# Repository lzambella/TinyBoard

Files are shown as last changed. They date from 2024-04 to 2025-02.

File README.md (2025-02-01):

40% keyboard based on a layout I found somewhere, possibly Reddit, and modified for my own tastes. Runs on TMK firmware.

**Switches**
Uses any Cherry full size 5-hole compatible ones. I like to use Gateron North Poles.

LEDs should be 1206 package.

TODO:
* Add STEP files for 3d printing/designing
* PDF files of schematics
* Better docs
* images
* how to build one?

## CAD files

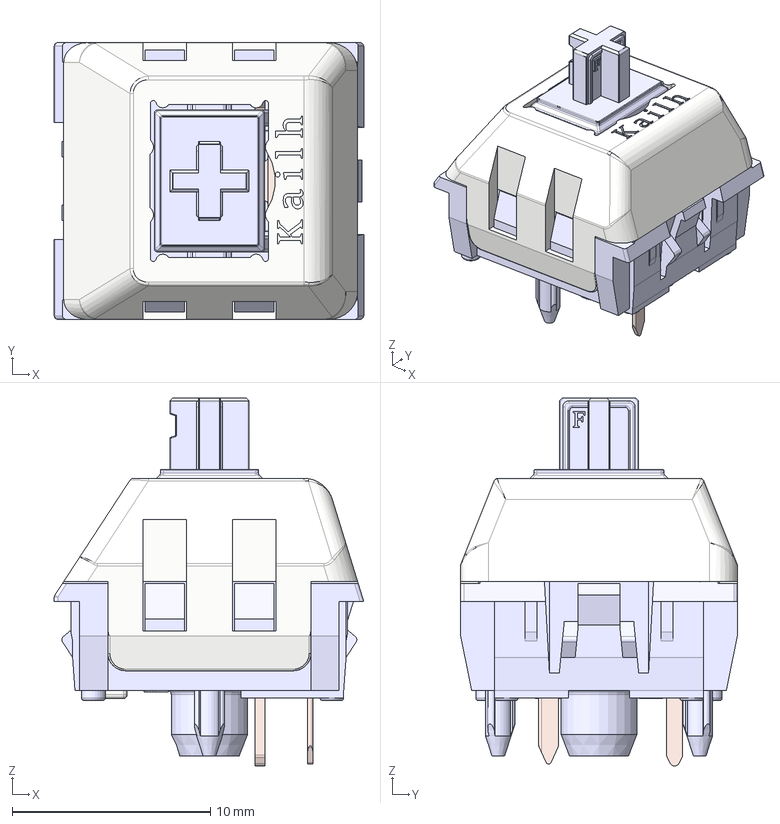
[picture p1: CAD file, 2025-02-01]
schematics/STEP files/KeySwitch.step
15.6 x 14.0 x 18.5 mm
Housing
ThickContact
SpringContact
Stem
Lid

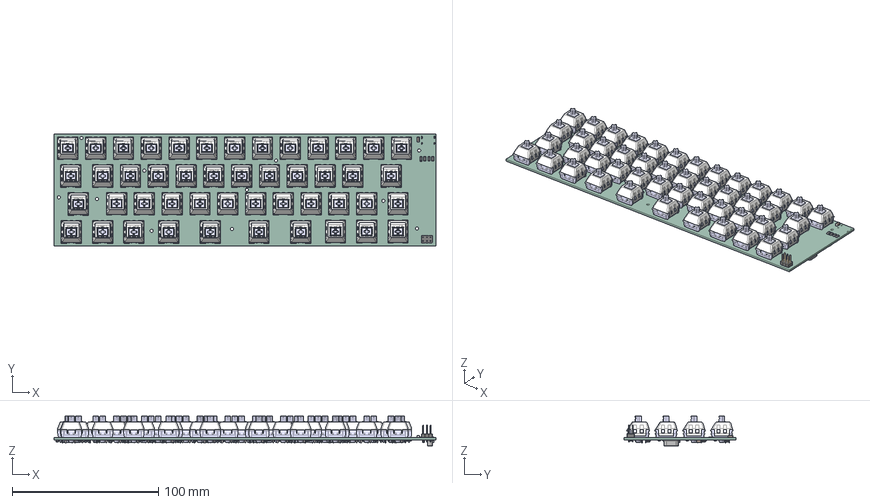
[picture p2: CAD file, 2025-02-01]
schematics/STEP files/PCB.step
261.1 x 76.2 x 20.4 mm
LED_1206_3216Metric x 47
Kailh Polia v86 x 47
C_1206_3216Metric x 4
R_1206_3216Metric x 51
PinHeader_2x03_P254mm_Vertical
D_SOD_123 x 47
Crystal_SMD_HC49-SD
_autosave-40 Keyboard_PCB

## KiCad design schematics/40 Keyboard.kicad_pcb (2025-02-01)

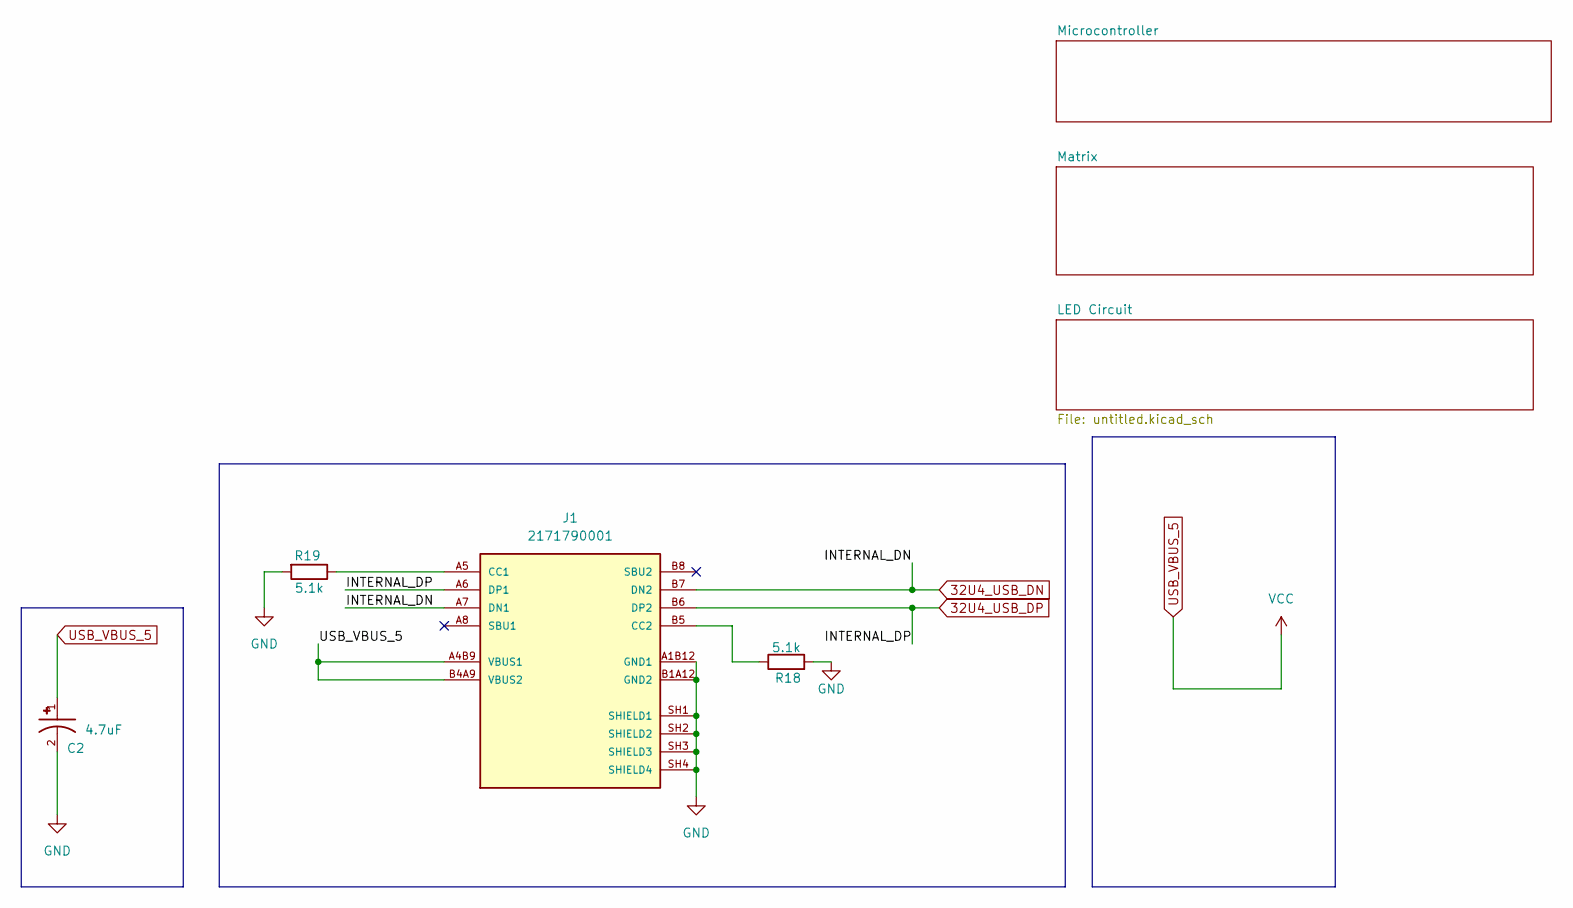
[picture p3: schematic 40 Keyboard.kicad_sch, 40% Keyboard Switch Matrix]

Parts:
C2: 4.7uF; C_1206_3216Metric_Pad1.33x1.80mm_HandSolder; Part # 311-2011-1-ND
J1: 2171790001; MOLEX_2171790001; PARTREV A1
R18, R19: 5.1k; R_1206_3216Metric; Part # RMCF1206JT5K10

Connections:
32U4_USB_DN: J1.A7 (DN1), J1.B7 (DN2); also elsewhere on the board
32U4_USB_DP: J1.A6 (DP1), J1.B6 (DP2); also elsewhere on the board
GND: C2.2, J1.A1B12 (GND1), J1.B1A12 (GND2), J1.SH1 (SHIELD1), J1.SH2 (SHIELD2), J1.SH3 (SHIELD3), J1.SH4 (SHIELD4), R18.2, R19.2; also elsewhere on the board
unnamed: J1.A5 (CC1), R19.1
unnamed: J1.B5 (CC2), R18.1
USB_VBUS_5: C2.1, J1.A4B9 (VBUS1), J1.B4A9 (VBUS2); also elsewhere on the board

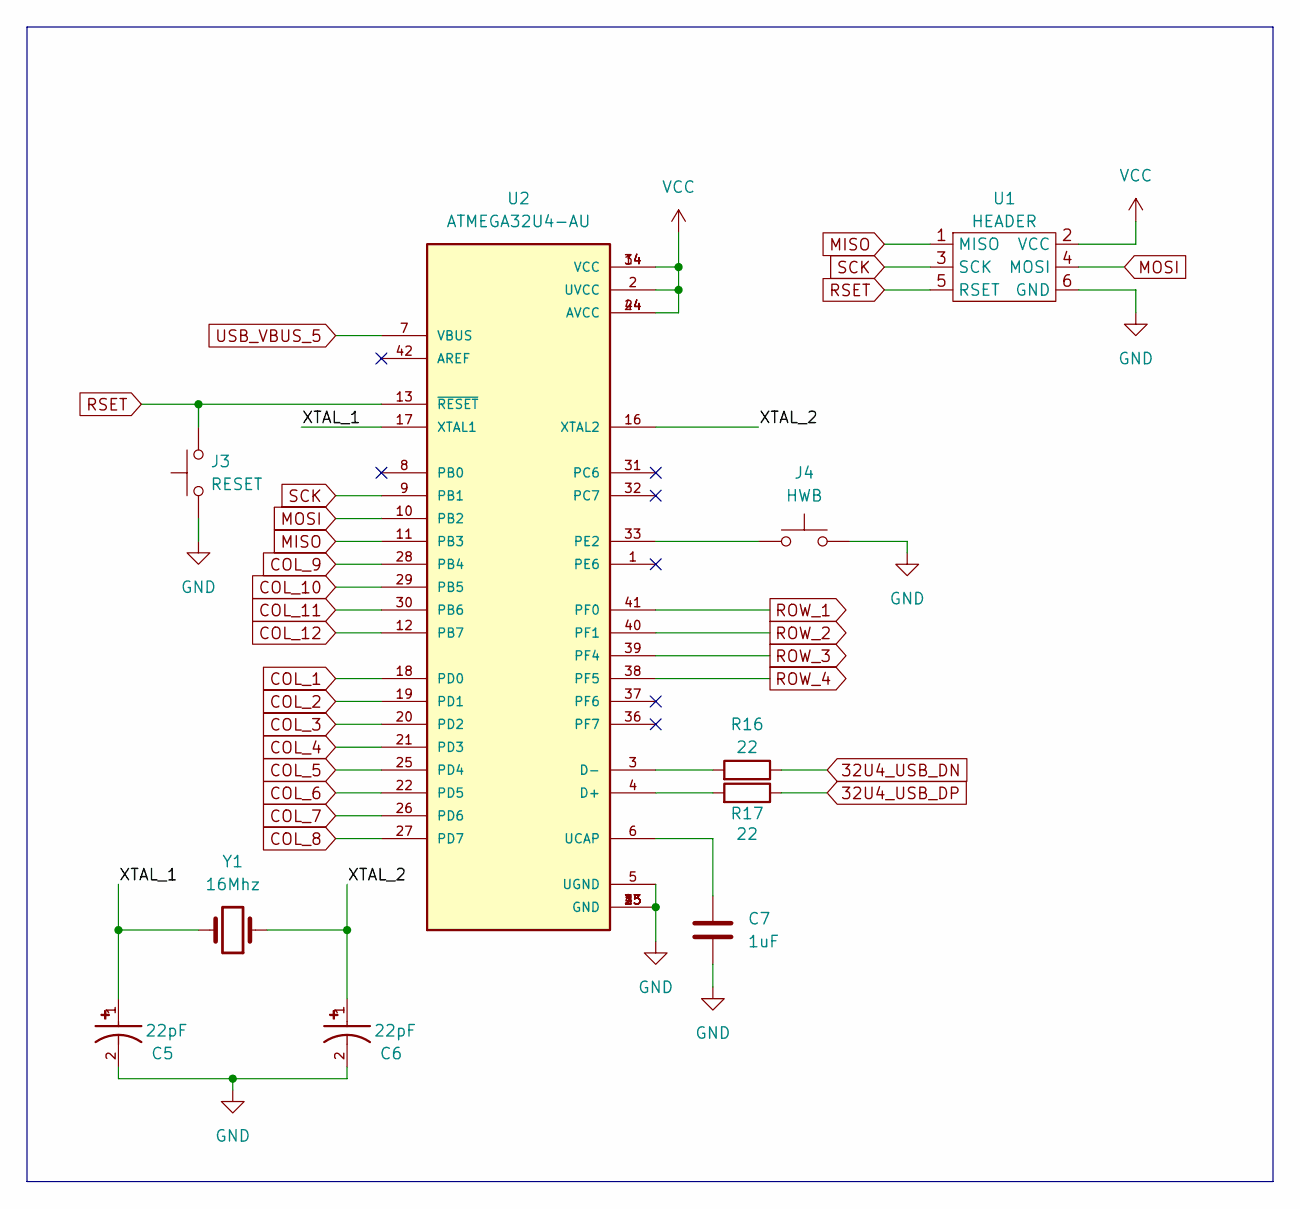
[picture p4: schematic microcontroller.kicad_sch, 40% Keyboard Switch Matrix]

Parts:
C5, C6: C1206C220K3HAC7800; C_1206_3216Metric_Pad1.33x1.80mm_HandSolder; Part # C1206C220K3HAC7800
C7: 1uF; C_1206_3216Metric; Part # C1206C104K5RAC7800
J3: RESET; SolderJumper-2_P1.3mm_Open_Pad1.0x1.5mm
J4: HWB; SolderJumper-2_P1.3mm_Open_Pad1.0x1.5mm
R16, R17: 22; R_1206_3216Metric; Part # RMCF1206JT22R0
U1: HEADER; PinHeader_2x03_P2.54mm_Vertical; Part # PH2-06-UA
U2: ATMEGA32U4-AU; atmega32u4; Part # ATMEGA32U4-AU-ND
Y1: 16Mhz; Crystal_SMD_HC49-SD_HandSoldering; Part # J49SMH-A-G-G-K-16M0

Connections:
32U4_USB_DN: R16.1; also elsewhere on the board
32U4_USB_DP: R17.1; also elsewhere on the board
/Microcontroller/XTAL_1: C5.1, U2.17 (XTAL1), Y1.2
/Microcontroller/XTAL_2: C6.1, U2.16 (XTAL2), Y1.1
COL_1: U2.18 (PD0); also elsewhere on the board
COL_2: U2.19 (PD1); also elsewhere on the board
COL_3: U2.20 (PD2); also elsewhere on the board
COL_4: U2.21 (PD3); also elsewhere on the board
COL_5: U2.25 (PD4); also elsewhere on the board
COL_6: U2.22 (PD5); also elsewhere on the board
COL_7: U2.26 (PD6); also elsewhere on the board
COL_8: U2.27 (PD7); also elsewhere on the board
COL_9: U2.28 (PB4); also elsewhere on the board
COL_10: U2.29 (PB5); also elsewhere on the board
COL_11: U2.30 (PB6); also elsewhere on the board
COL_12: U2.12 (PB7); also elsewhere on the board
GND: C5.2, C6.2, C7.2, J3.1, J4.2, U1.6 (GND), U2.5 (UGND), U2.15 (GND), U2.23 (GND), U2.35 (GND), U2.43 (GND); also elsewhere on the board
MISO: U1.1 (MISO), U2.11 (PB3)
MOSI: U1.4 (MOSI), U2.10 (PB2)
unnamed: R17.2, U2.4 (D+)
unnamed: R16.2, U2.3 (D-)
unnamed: J4.1, U2.33 (PE2)
unnamed: C7.1, U2.6 (UCAP)
ROW_1: U2.41 (PF0); also elsewhere on the board
ROW_2: U2.40 (PF1); also elsewhere on the board
ROW_3: U2.39 (PF4); also elsewhere on the board
ROW_4: U2.38 (PF5); also elsewhere on the board
RSET: J3.2, U1.5 (RSET), U2.13 (~RESET)
SCK: U1.3 (SCK), U2.9 (PB1)
USB_VBUS_5: U1.2 (VCC), U2.2 (UVCC), U2.7 (VBUS), U2.14 (VCC), U2.24 (AVCC), U2.34 (VCC), U2.44 (AVCC); also elsewhere on the board

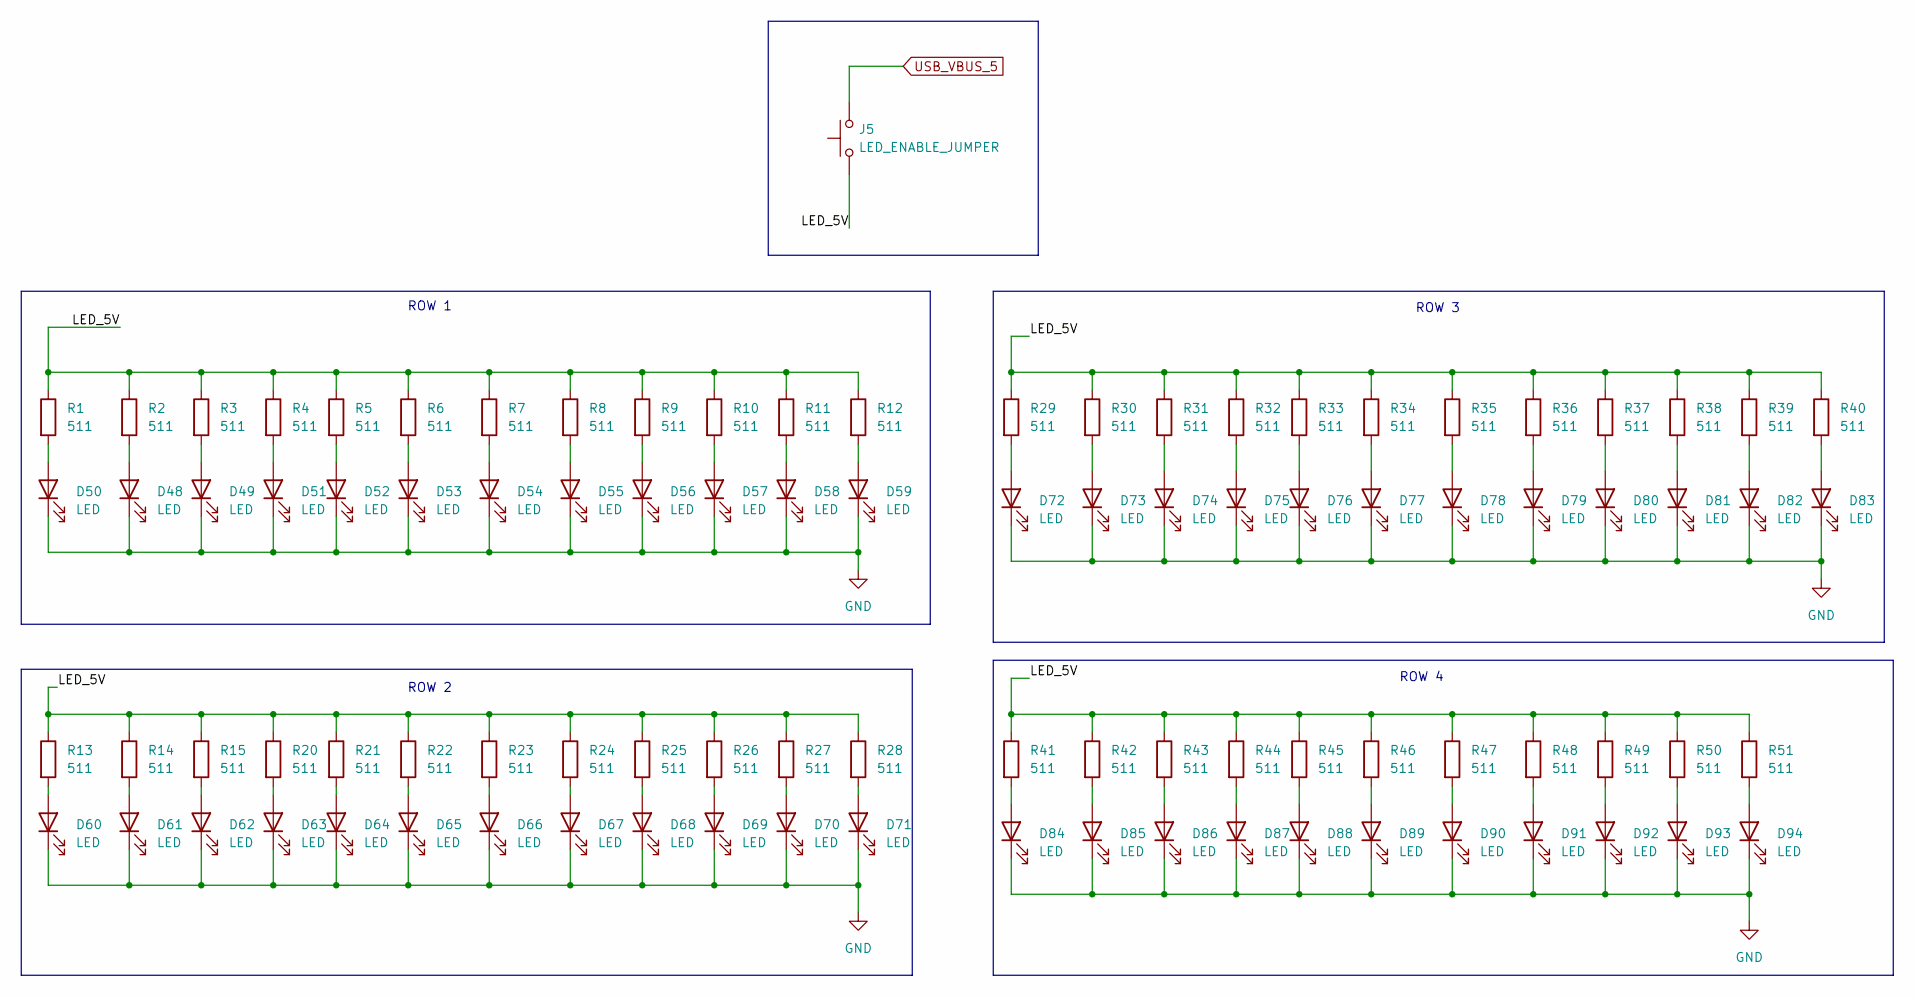
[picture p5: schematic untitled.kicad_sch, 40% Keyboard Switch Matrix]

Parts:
D48, D49, D50, D51, D52, D53, D54, D55, D56, D57, D58, D59, D60, D61, D62, D63, D64, D65, D66, D67, D68, D69, D70, D71, D72, D73, D74, D75, D76, D77, D78, D79, D80, D81, D82, D83, D84, D85, D86, D87, D88, D89, D90, D91, D92, D93, D94: LED; LED_1206_3216Metric_Pad1.42x1.75mm_HandSolder; Part # 732-4988-1-ND
J5: LED_ENABLE_JUMPER; SolderJumper-2_P1.3mm_Open_Pad1.0x1.5mm
R1, R2, R3, R4, R5, R6, R7, R8, R9, R10, R11, R12, R13, R14, R15, R20, R21, R22, R23, R24, R25, R26, R27, R28, R29, R30, R31, R32, R33, R34, R35, R36, R37, R38, R39, R40, R41, R42, R43, R44, R45, R46, R47, R48, R49, R50, R51: 511; R_1206_3216Metric_Pad1.30x1.75mm_HandSolder; Part # RNCP1206FTD511RCT-ND

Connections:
/LED Circuit/LED_5V: J5.1, R1.1, R2.1, R3.1, R4.1, R5.1, R6.1, R7.1, R8.1, R9.1, R10.1, R11.1, R12.1, R13.1, R14.1, R15.1, R20.1, R21.1, R22.1, R23.1, R24.1, R25.1, R26.1, R27.1, R28.1, R29.1, R30.1, R31.1, R32.1, R33.1, R34.1, R35.1, R36.1, R37.1, R38.1, R39.1, R40.1, R41.1, R42.1, R43.1, R44.1, R45.1, R46.1, R47.1, R48.1, R49.1, R50.1, R51.1
GND: D48.1 (K), D49.1 (K), D50.1 (K), D51.1 (K), D52.1 (K), D53.1 (K), D54.1 (K), D55.1 (K), D56.1 (K), D57.1 (K), D58.1 (K), D59.1 (K), D60.1 (K), D61.1 (K), D62.1 (K), D63.1 (K), D64.1 (K), D65.1 (K), D66.1 (K), D67.1 (K), D68.1 (K), D69.1 (K), D70.1 (K), D71.1 (K), D72.1 (K), D73.1 (K), D74.1 (K), D75.1 (K), D76.1 (K), D77.1 (K), D78.1 (K), D79.1 (K), D80.1 (K), D81.1 (K), D82.1 (K), D83.1 (K), D84.1 (K), D85.1 (K), D86.1 (K), D87.1 (K), D88.1 (K), D89.1 (K), D90.1 (K), D91.1 (K), D92.1 (K), D93.1 (K), D94.1 (K); also elsewhere on the board
unnamed: D48.2 (A), R2.2
unnamed: D49.2 (A), R3.2
unnamed: D50.2 (A), R1.2
unnamed: D51.2 (A), R4.2
unnamed: D52.2 (A), R5.2
unnamed: D53.2 (A), R6.2
unnamed: D54.2 (A), R7.2
unnamed: D55.2 (A), R8.2
unnamed: D56.2 (A), R9.2
unnamed: D57.2 (A), R10.2
unnamed: D58.2 (A), R11.2
unnamed: D59.2 (A), R12.2
unnamed: D60.2 (A), R13.2
unnamed: D61.2 (A), R14.2
unnamed: D62.2 (A), R15.2
unnamed: D63.2 (A), R20.2
unnamed: D64.2 (A), R21.2
unnamed: D65.2 (A), R22.2
unnamed: D66.2 (A), R23.2
unnamed: D67.2 (A), R24.2
unnamed: D68.2 (A), R25.2
unnamed: D69.2 (A), R26.2
unnamed: D70.2 (A), R27.2
unnamed: D71.2 (A), R28.2
unnamed: D72.2 (A), R29.2
unnamed: D73.2 (A), R30.2
unnamed: D74.2 (A), R31.2
unnamed: D75.2 (A), R32.2
unnamed: D76.2 (A), R33.2
unnamed: D77.2 (A), R34.2
unnamed: D78.2 (A), R35.2
unnamed: D79.2 (A), R36.2
unnamed: D80.2 (A), R37.2
unnamed: D81.2 (A), R38.2
unnamed: D82.2 (A), R39.2
unnamed: D83.2 (A), R40.2
unnamed: D84.2 (A), R41.2
unnamed: D85.2 (A), R42.2
unnamed: D86.2 (A), R43.2
unnamed: D87.2 (A), R44.2
unnamed: D88.2 (A), R45.2
unnamed: D89.2 (A), R46.2
unnamed: D90.2 (A), R47.2
unnamed: D91.2 (A), R48.2
unnamed: D92.2 (A), R49.2
unnamed: D93.2 (A), R50.2
unnamed: D94.2 (A), R51.2
USB_VBUS_5: J5.2; also elsewhere on the board

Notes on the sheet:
ROW 2
ROW 4
ROW 3
ROW 1

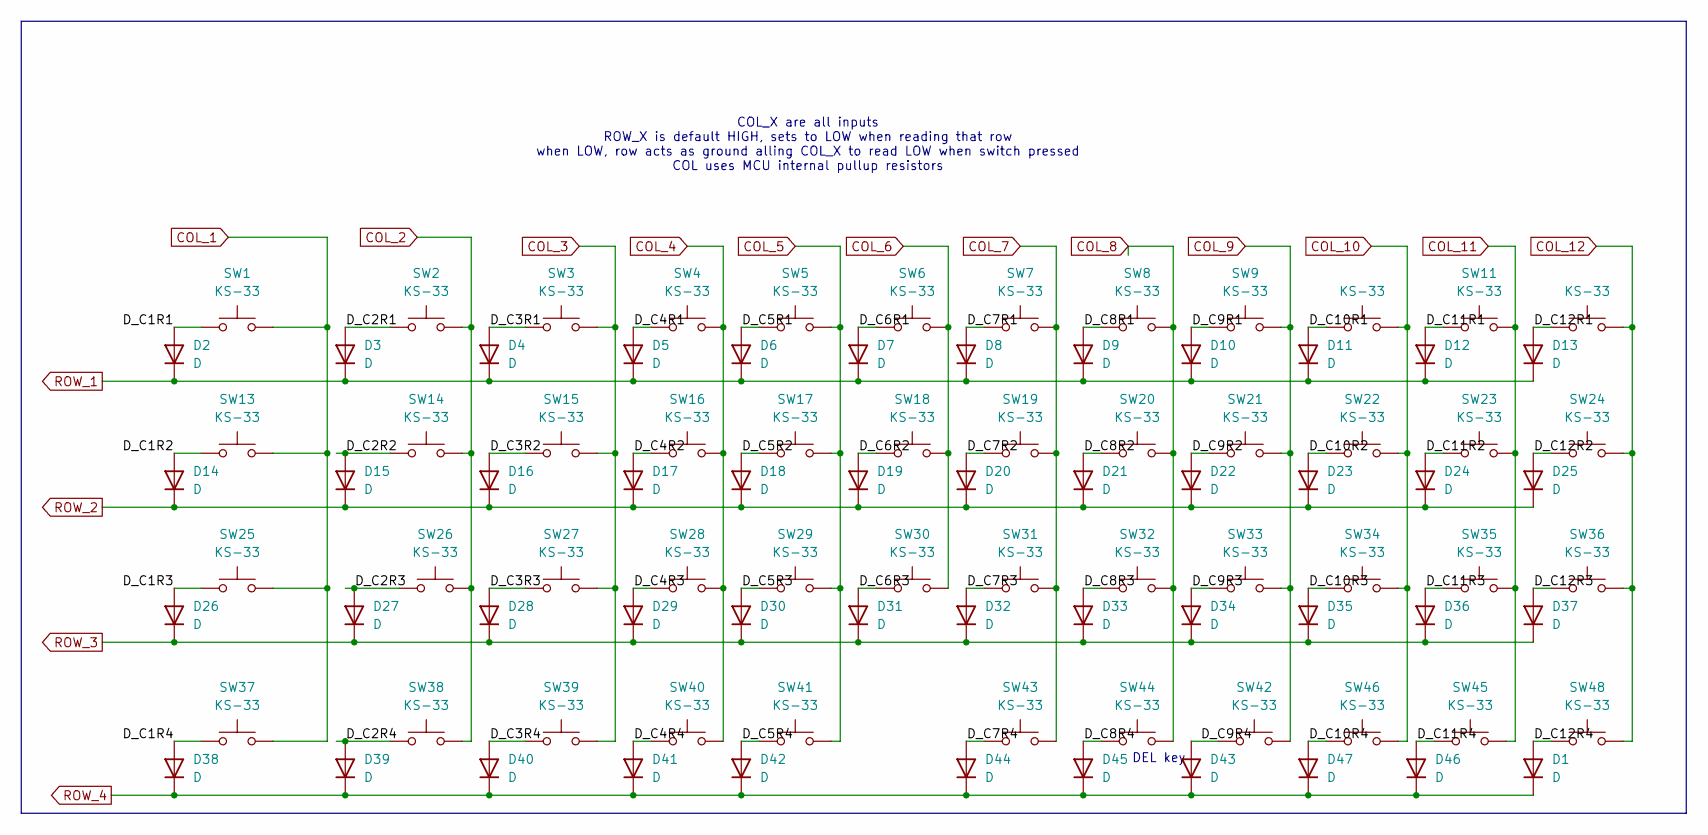
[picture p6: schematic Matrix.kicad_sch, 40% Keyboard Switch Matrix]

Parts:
D1, D2, D3, D4, D5, D6, D7, D8, D9, D10, D11, D12, D13, D14, D15, D16, D17, D18, D19, D20, D21, D22, D23, D24, D25, D26, D27, D28, D29, D30, D31, D32, D33, D34, D35, D36, D37, D38, D39, D40, D41, D42, D43, D44, D45, D46, D47: D; D_SOD-123; Part # 1N4148W-TP
SW1, SW2, SW3, SW4, SW5, SW6, SW7, SW8, SW9, SW10, SW11, SW12, SW13, SW14, SW15, SW16, SW17, SW18, SW19, SW20, SW21, SW22, SW23, SW24, SW25, SW26, SW27, SW28, SW29, SW30, SW31, SW32, SW33, SW34, SW35, SW36, SW37, SW38, SW39, SW40, SW41, SW42, SW43, SW44, SW45, SW46, SW48: KS-33; Cherry MX switch

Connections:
/Matrix/D_C1R1: D2.2 (A), SW1.1
/Matrix/D_C1R2: D14.2 (A), SW13.1
/Matrix/D_C1R3: D26.2 (A), SW25.1
/Matrix/D_C1R4: D38.2 (A), SW37.1
/Matrix/D_C2R1: D3.2 (A), SW2.1
/Matrix/D_C2R2: D15.2 (A), SW14.1
/Matrix/D_C2R3: D27.2 (A), SW26.1
/Matrix/D_C2R4: D39.2 (A), SW38.1
/Matrix/D_C3R1: D4.2 (A), SW3.1
/Matrix/D_C3R2: D16.2 (A), SW15.1
/Matrix/D_C3R3: D28.2 (A), SW27.1
/Matrix/D_C3R4: D40.2 (A), SW39.1
/Matrix/D_C4R1: D5.2 (A), SW4.1
/Matrix/D_C4R2: D17.2 (A), SW16.1
/Matrix/D_C4R3: D29.2 (A), SW28.1
/Matrix/D_C4R4: D41.2 (A), SW40.1
/Matrix/D_C5R1: D6.2 (A), SW5.1
/Matrix/D_C5R2: D18.2 (A), SW17.1
/Matrix/D_C5R3: D30.2 (A), SW29.1
/Matrix/D_C5R4: D42.2 (A), SW41.1
/Matrix/D_C6R1: D7.2 (A), SW6.1
/Matrix/D_C6R2: D19.2 (A), SW18.1
/Matrix/D_C6R3: D31.2 (A), SW30.1
/Matrix/D_C7R1: D8.2 (A), SW7.1
/Matrix/D_C7R2: D20.2 (A), SW19.1
/Matrix/D_C7R3: D32.2 (A), SW31.1
/Matrix/D_C7R4: D44.2 (A), SW43.1
/Matrix/D_C8R1: D9.2 (A), SW8.1
/Matrix/D_C8R2: D21.2 (A), SW20.1
/Matrix/D_C8R3: D33.2 (A), SW32.1
/Matrix/D_C8R4: D45.2 (A), SW44.1
/Matrix/D_C9R1: D10.2 (A), SW9.1
/Matrix/D_C9R2: D22.2 (A), SW21.1
/Matrix/D_C9R3: D34.2 (A), SW33.1
/Matrix/D_C9R4: D43.2 (A), SW42.1
/Matrix/D_C10R1: D11.2 (A), SW10.1
/Matrix/D_C10R2: D23.2 (A), SW22.1
/Matrix/D_C10R3: D35.2 (A), SW34.1
/Matrix/D_C10R4: D47.2 (A), SW46.1
/Matrix/D_C11R1: D12.2 (A), SW11.1
/Matrix/D_C11R2: D24.2 (A), SW23.1
/Matrix/D_C11R3: D36.2 (A), SW35.1
/Matrix/D_C11R4: D46.2 (A), SW45.1
/Matrix/D_C12R1: D13.2 (A), SW12.1
/Matrix/D_C12R2: D25.2 (A), SW24.1
/Matrix/D_C12R3: D37.2 (A), SW36.1
/Matrix/D_C12R4: D1.2 (A), SW48.1
COL_1: SW1.2, SW13.2, SW25.2, SW37.2; also elsewhere on the board
COL_2: SW2.2, SW14.2, SW26.2, SW38.2; also elsewhere on the board
COL_3: SW3.2, SW15.2, SW27.2, SW39.2; also elsewhere on the board
COL_4: SW4.2, SW16.2, SW28.2, SW40.2; also elsewhere on the board
COL_5: SW5.2, SW17.2, SW29.2, SW41.2; also elsewhere on the board
COL_6: SW6.2, SW18.2, SW30.2; also elsewhere on the board
COL_7: SW7.2, SW19.2, SW31.2, SW43.2; also elsewhere on the board
COL_8: SW8.2, SW20.2, SW32.2, SW44.2; also elsewhere on the board
COL_9: SW9.2, SW21.2, SW33.2, SW42.2; also elsewhere on the board
COL_10: SW10.2, SW22.2, SW34.2, SW46.2; also elsewhere on the board
COL_11: SW11.2, SW23.2, SW35.2, SW45.2; also elsewhere on the board
COL_12: SW12.2, SW24.2, SW36.2, SW48.2; also elsewhere on the board
ROW_1: D2.1 (K), D3.1 (K), D4.1 (K), D5.1 (K), D6.1 (K), D7.1 (K), D8.1 (K), D9.1 (K), D10.1 (K), D11.1 (K), D12.1 (K), D13.1 (K); also elsewhere on the board
ROW_2: D14.1 (K), D15.1 (K), D16.1 (K), D17.1 (K), D18.1 (K), D19.1 (K), D20.1 (K), D21.1 (K), D22.1 (K), D23.1 (K), D24.1 (K), D25.1 (K); also elsewhere on the board
ROW_3: D26.1 (K), D27.1 (K), D28.1 (K), D29.1 (K), D30.1 (K), D31.1 (K), D32.1 (K), D33.1 (K), D34.1 (K), D35.1 (K), D36.1 (K), D37.1 (K); also elsewhere on the board
ROW_4: D1.1 (K), D38.1 (K), D39.1 (K), D40.1 (K), D41.1 (K), D42.1 (K), D43.1 (K), D44.1 (K), D45.1 (K), D46.1 (K), D47.1 (K); also elsewhere on the board

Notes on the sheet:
DEL key
COL_X are all inputs ROW_X is default HIGH, sets to LOW when reading that row when LOW, row acts as ground alling COL_X to read LOW when switch pressed COL uses MCU internal pullup resistors

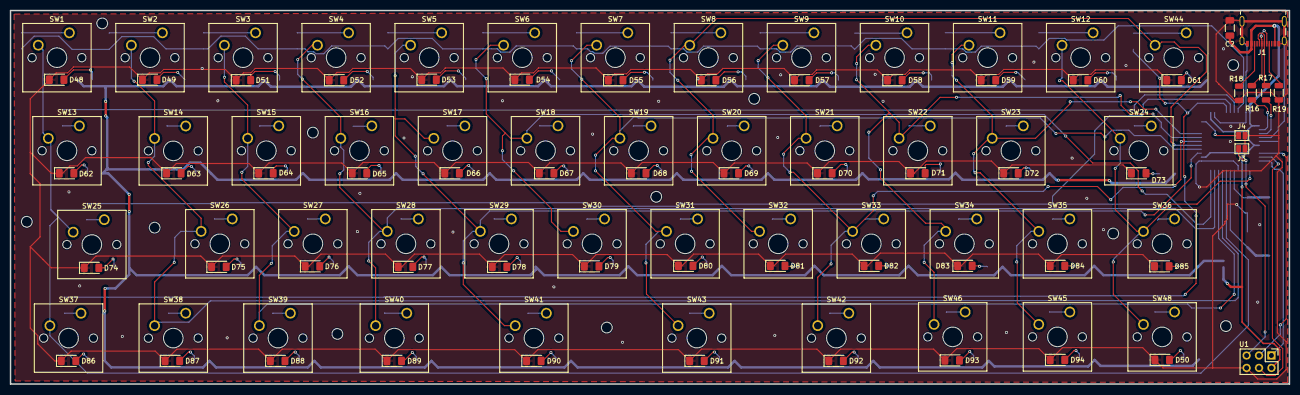
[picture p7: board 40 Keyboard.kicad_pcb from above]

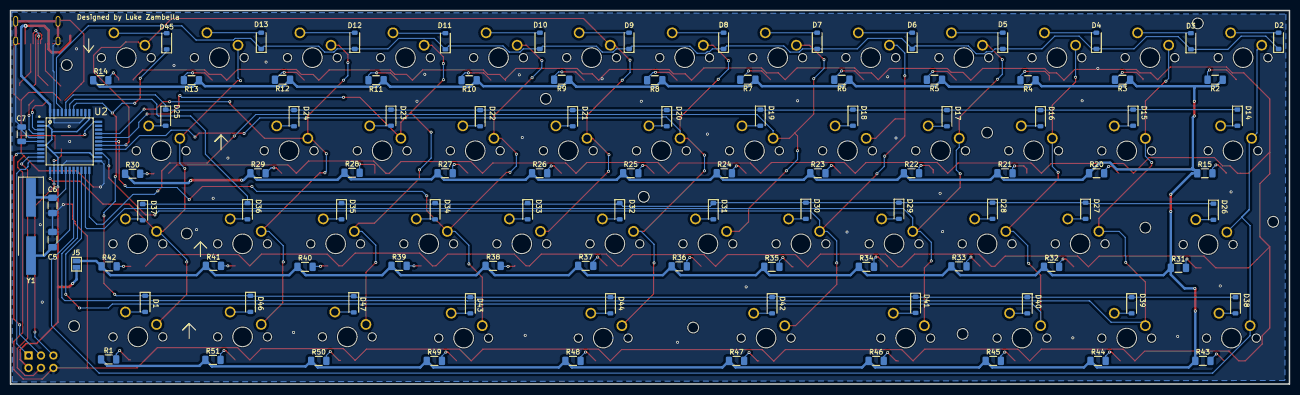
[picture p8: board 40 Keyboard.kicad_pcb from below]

Board: 2 copper layers, 261.1 x 76.2 mm, 203 parts (100 on the bottom side), 127 nets.

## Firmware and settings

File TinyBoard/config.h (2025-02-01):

/*
Copyright 2012 Jun Wako <wakojun@gmail.com>

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
You should have received a copy of the GNU General Public License
along with this program.  If not, see <http://www.gnu.org/licenses/>.
*/

/*
Modified by Luke Zambella
All buttons are resisitive pull up (IE pressing sends a LOW to mcu pin)
*/

#ifndef CONFIG_H
#define CONFIG_H


/* USB Device descriptor parameter */
#define VENDOR_ID       0x6FFE
#define PRODUCT_ID      0x4759
#define DEVICE_VER      0x0001
#define MANUFACTURER    LukeZambella
#define PRODUCT         DragonBoard
#define DESCRIPTION     DragonBoardKeyboard

/* key matrix size */
#define MATRIX_ROWS 4
#define MATRIX_COLS 12

/* define if matrix has ghost */
//#define MATRIX_HAS_GHOST

/* Set 0 if debouncing isn't needed */
#define DEBOUNCE    10

/* Mechanical locking support. Use KC_LCAP, KC_LNUM or KC_LSCR instead in keymap */
//#define LOCKING_SUPPORT_ENABLE
/* Locking resynchronize hack */
//#define LOCKING_RESYNC_ENABLE

/* key combination for command */
#define IS_COMMAND() ( \
    keyboard_report->mods == (MOD_BIT(KC_LSHIFT) | MOD_BIT(KC_RSHIFT)) \
)

/*
 * Feature disable options
 *  These options are also useful to firmware size reduction.
 */

/* disable debug print */
//#define NO_DEBUG

/* disable print */
//#define NO_PRINT

/* disable action features */
//#define NO_ACTION_LAYER
//#define NO_ACTION_TAPPING
//#define NO_ACTION_ONESHOT
//#define NO_ACTION_MACRO
//#define NO_ACTION_FUNCTION


/* PS/2 mouse */
#ifdef PS2_USE_BUSYWAIT
#   define PS2_CLOCK_PORT  PORTD
#   define PS2_CLOCK_PIN   PIND
#   define PS2_CLOCK_DDR   DDRD
#   define PS2_CLOCK_BIT   1
#   define PS2_DATA_PORT   PORTD
#   define PS2_DATA_PIN    PIND
#   define PS2_DATA_DDR    DDRD
#   define PS2_DATA_BIT    2
#endif


/* PS/2 mouse interrupt version */
#ifdef PS2_USE_INT
/* uses INT1 for clock line(ATMega32U4) */
#define PS2_CLOCK_PORT  PORTD
#define PS2_CLOCK_PIN   PIND
#define PS2_CLOCK_DDR   DDRD
#define PS2_CLOCK_BIT   1
#define PS2_DATA_PORT   PORTD
#define PS2_DATA_PIN    PIND
#define PS2_DATA_DDR    DDRD
#define PS2_DATA_BIT    2

#define PS2_INT_INIT()  do {    \
    EICRA |= ((1<<ISC11) |      \
              (0<<ISC10));      \
} while (0)
#define PS2_INT_ON()  do {      \
    EIMSK |= (1<<INT1);         \
} while (0)
#define PS2_INT_OFF() do {      \
    EIMSK &= ~(1<<INT1);        \
} while (0)
#define PS2_INT_VECT    INT1_vect
#endif


/* PS/2 mouse USART version */
#ifdef PS2_USE_USART
#if defined(__AVR_ATmega16U4__) || defined(__AVR_ATmega32U4__)
/* XCK for clock line and RXD for data line */
#define PS2_CLOCK_PORT  PORTD
#define PS2_CLOCK_PIN   PIND
#define PS2_CLOCK_DDR   DDRD
#define PS2_CLOCK_BIT   5
#define PS2_DATA_PORT   PORTD
#define PS2_DATA_PIN    PIND
#define PS2_DATA_DDR    DDRD
#define PS2_DATA_BIT    2

/* synchronous, odd parity, 1-bit stop, 8-bit data, sample at falling edge */
/* set DDR of CLOCK as input to be slave */
#define PS2_USART_INIT() do {   \
    PS2_CLOCK_DDR &= ~(1<<PS2_CLOCK_BIT);   \
    PS2_DATA_DDR &= ~(1<<PS2_DATA_BIT);     \
    UCSR1C = ((1 << UMSEL10) |  \
              (3 << UPM10)   |  \
              (0 << USBS1)   |  \
              (3 << UCSZ10)  |  \
              (0 << UCPOL1));   \
    UCSR1A = 0;                 \
    UBRR1H = 0;                 \
    UBRR1L = 0;                 \
} while (0)
#define PS2_USART_RX_INT_ON() do {  \
    UCSR1B = ((1 << RXCIE1) |       \
              (1 << RXEN1));        \
} while (0)
#define PS2_USART_RX_POLL_ON() do { \
    UCSR1B = (1 << RXEN1);          \
} while (0)
#define PS2_USART_OFF() do {    \
    UCSR1C = 0;                 \
    UCSR1B &= ~((1 << RXEN1) |  \
                (1 << TXEN1));  \
} while (0)
#define PS2_USART_RX_READY      (UCSR1A & (1<<RXC1))
#define PS2_USART_RX_DATA       UDR1
#define PS2_USART_ERROR         (UCSR1A & ((1<<FE1) | (1<<DOR1) | (1<<UPE1)))
#define PS2_USART_RX_VECT       USART1_RX_vect
#endif
#endif

#endif

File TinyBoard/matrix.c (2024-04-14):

#include <stdint.h>
#include <stdbool.h>
#include <avr/io.h>
#include <util/delay.h>
#include "matrix.h"
#include "debug.h"
#include "config.h"

// Variable to store the current row
static uint8_t debouncing = DEBOUNCE;

static matrix_row_t matrix[MATRIX_ROWS];
static matrix_row_t matrix_debouncing[MATRIX_ROWS];

// Function definitions
static matrix_row_t read_cols(void);
static void unselect_rows(void);
static void select_row(uint8_t row);

void matrix_init(void) {
    MCUCR |= (1<<JTD);
    MCUCR |= (1<<JTD);

    // Set row pins to output
    // PORF 0,1,4,5 >> ROW 1,2,3,4
    DDRF |= (1 << 0);
    DDRF |= (1 << 1);
    DDRF |= (1 << 4);
    DDRF |= (1 << 5);

    // Initialize all rows to HIGH
    PORTF |= (1 << PF0);
    PORTF |= (1 << PF1);
    PORTF |= (1 << PF4);
    PORTF |= (1 << PF5);
    
    // Set column pins as input
    DDRF &= ~(1 << 6); // col 1

    DDRB &= ~(1 << 6); // 2
    DDRB &= ~(1 << 5); // 3
    DDRB &= ~(1 << 4); // 4
    DDRB &= ~(1 << 3); // 5
    DDRB &= ~(1 << 2); // 6
    DDRB &= ~(1 << 1); // 7
    DDRB &= ~(1 << 0); // 8

    DDRC &= ~(1 << 6); // 9
    DDRC &= ~(1 << 7); // 10

    DDRD &= ~(1 << 0); // 11
    DDRD &= ~(1 << 1); // 12

    // Disable internal pull ups on col
    PORTF &= ~(1 << 6); // col 1

    PORTB &= ~(1 << 6); // 2
    PORTB &= ~(1 << 5); // 3
    PORTB &= ~(1 << 4); // 4
    PORTB &= ~(1 << 3); // 5
    PORTB &= ~(1 << 2); // 6
    PORTB &= ~(1 << 1); // 7
    PORTB &= ~(1 << 0); // 8

    PORTC &= ~(1 << 6); // 9
    PORTC &= ~(1 << 7); // 10

    PORTD &= ~(1 << 0); // 11
    PORTD &= ~(1 << 1); // 12

    // make sure matrix is cleared on init
    for (int i = 0; i < MATRIX_ROWS; i++) { 
        matrix[i] = 0;
        matrix_debouncing[i] = 0;
    }
}

uint8_t matrix_scan(void) {
    debug("Scan row\n");
    for (uint8_t i = 0; i < MATRIX_ROWS; i++) {
        select_row(i);
        _delay_us(100);  // without this wait read unstable value.
        matrix_row_t cols = read_cols();
        if (matrix_debouncing[i] != cols) {
            matrix_debouncing[i] = cols;
            if (debouncing) {
                debug("bounce!: "); debug_hex(debouncing); debug("\n");
            }
            debouncing = DEBOUNCE;
        }
        unselect_rows();
    }

    if (debouncing) {
        if (--debouncing) {
            _delay_ms(1);
        } else {
            for (uint8_t i = 0; i < MATRIX_ROWS; i++) {
                matrix[i] = matrix_debouncing[i];
            }
        }
    }

    return 1;
}

/*
* Deselects rows by writing a HIGH to all the row pins
*/
static void unselect_rows(void)
{
    PORTF |= (1 << PF0);
    PORTF |= (1 << PF1);
    PORTF |= (1 << PF4);
    PORTF |= (1 << PF5);
}

/*
* Get a single row in the matrix array
* Each row contains bits that represent the columns in the matrix
*/
matrix_row_t matrix_get_row(uint8_t row)
{
    return matrix[row];
}

/*
* Reads all of the columns into an integer
*/
static matrix_row_t read_cols()
{
    // Get the state of the columns

    // If we read a LOW at the pin input (switch pressed) we want the variable to be HIGH
    uint16_t c1 =  ((~PINF & (1 << 6)) >> 6); // F6

    uint16_t c2 =  ((~PINB & (1 << 6)) >> 6); // B6
    uint16_t c3 =  ((~PINB & (1 << 5)) >> 5); // B5
    uint16_t c4 =  ((~PINB & (1 << 4)) >> 4); // B4
    uint16_t c5 =  ((~PINB & (1 << 3)) >> 3); // B3
    uint16_t c6 =  ((~PINB & (1 << 2)) >> 2); // B2
    uint16_t c7 =  ((~PINB & (1 << 1)) >> 1); // B1
    uint16_t c8 =  ((~PINB & (1 << 0)) >> 0); // B0

    uint16_t c9 =  ((~PINC & (1 << 6)) >> 6); // C6
    uint16_t c10 = ((~PINC & (1 << 7)) >> 7); // C7

    uint16_t c11 = ((~PIND & (1 << 0)) >> 0); // D0
    uint16_t c12 = ((~PIND & (1 << 1)) >> 1); // D1

    // Make a continuous integer of the inputs
    matrix_row_t C = 0;

    C = C | c1  << 0;
    C = C | c2  << 1;
    C = C | c3  << 2;
    C = C | c4  << 3;
    C = C | c5  << 4;
    C = C | c6  << 5;
    C = C | c7  << 6;
    C = C | c8  << 7;
    C = C | c9  << 8;
    C = C | c10 << 9;
    C = C | c11 << 10;
    C = C | c12 << 11;

    debug_bin16(C); debug("\n");
    return C;
}

/**
 * Select a row by writing LOW to it
*/
static void select_row(uint8_t row)
{
    switch (row) {
        // Row 1 (pin F0)
        case 0:
            DDRF |= (1 << DDF0);
            PORTF &= ~(1 << PF0); 
            break;
        case 1:
        // Row 2 (pin F1)
            DDRF |= (1 << DDF1);
            PORTF &= ~(1 << PF1); 
            break;
        case 2:
        // Row 3 (Pin F4)
            DDRF |= (1 << DDF4);
            PORTF &= ~(1 << PF4);
            break;
        case 3:
        // Row 4 (Pin F5)
            DDRF |= (1 << DDF5);
            PORTF &= ~(1 << PF5); 
            break;
    }
}

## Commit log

2024-04-19 Update key layout, increase debounce, PCB update
    [40 Keyboard.kicad_pcb, 40 Keyboard.kicad_sch, KeySwitch.step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]
2024-05-03 Update schematic and board layout
    [40 Keyboard.kicad_pcb, 40 Keyboard.kicad_sch, Wookiee Cherry.1 1.25u.STL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]
2025-02-01 Update project to use Rev2 final board
    [40 Keyboard-B_Cu.gbr, 40 Keyboard-B_Mask.gbr, 40 Keyboard-B_Paste.gbr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]

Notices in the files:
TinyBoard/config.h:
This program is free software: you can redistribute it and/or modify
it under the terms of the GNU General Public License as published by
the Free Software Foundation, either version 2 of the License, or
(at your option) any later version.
